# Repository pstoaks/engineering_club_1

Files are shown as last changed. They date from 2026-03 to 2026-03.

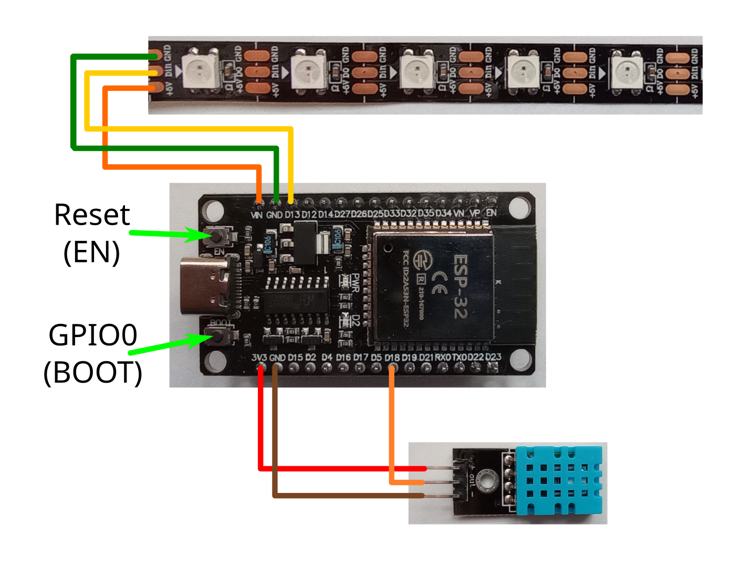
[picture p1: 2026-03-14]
docs/wiring_diagram.png

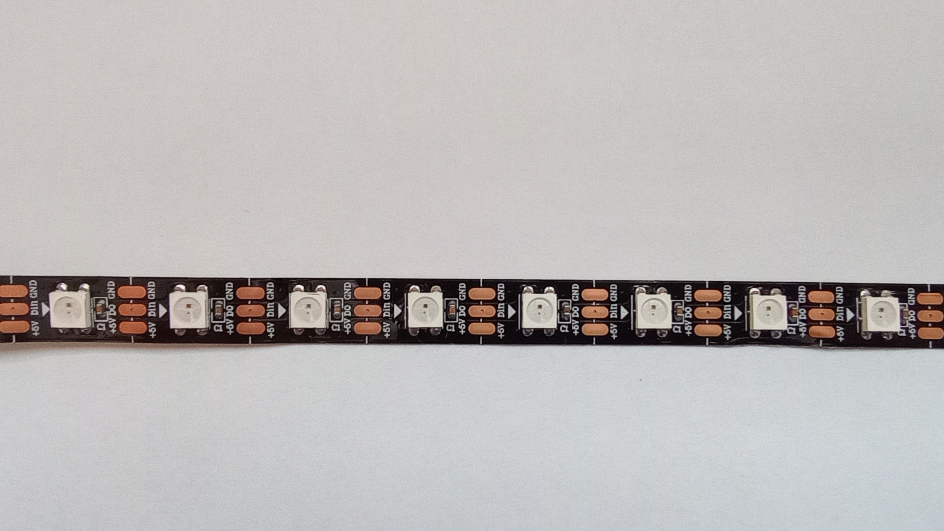
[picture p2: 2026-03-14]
docs/images/WS2812B_Light_Strip_Photo.jpg

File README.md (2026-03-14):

# Introduction to Engineering Course Plan

## 5-Week Course for Ages 12-18

### Course Overview

This course introduces students to the engineering process and disciplines (mechanical, electrical, and software) through hands-on learning. Students will build a complete IoT environmental monitor that senses temperature/humidity and displays the data using colorful LED patterns in a 3D-printed enclosure. OpenSCAD, STL and Tinkercad building blocks are provided to help with the more difficult 3D design bits.

- Week 1: Introduction to Engineering and Requirements Analysis
- Week 2: Mechanical Engineering
- Week 3: Electrical/Electronics Engineering
- Week 4: Software Development
- Week 5: Putting it all together: integration

### Learning Objectives

- Understand what engineers do in electrical, mechanical, and software disciplines
- Experience the engineering design process from requirements to final product
- Gain hands-on experience with circuits, programming, and 3D design
- Develop problem-solving and troubleshooting skills
- Make informed decisions about pursuing engineering education and careers

### Final Project

**IoT Environmental Monitor**

- ESP32 microcontroller development board
- Temperature/humidity sensor (DHT11)
- Addressable LED strip (WS2812B, 10 LEDs)
- Multiple display modes with plug-in architecture for students to design their own
- Optional web server with web application to monitor temperature and humidity and to control the mode.
- Custom, student-designed, 3D-printed enclosure
- USB power

### Purchased parts used in this course:
* ESP32 Microcontroller Development Board: https://www.amazon.com/DORHEA-Development-Bluetooth-ESP-WROOM-32-ESP32-DevKitC-32/dp/B0B18NK2MS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
* DHT11 Temperature & Humidity Sensor: https://www.amazon.com/dp/B0DTKB16MD?ref_=ppx_hzsearch_conn_dt_b_fed_asin_title_1
* WS2812B LED strip, 10 LEDs, 16.5 mm pitch.

A description of the development board being used can be found here:
https://lastminuteengineers.com/esp32-pinout-reference/

### Software Used:
  - Thonny for software development (https://thonny.org/)
  - Tinkercad for 3D modeling and design (https://www.tinkercad.com/)
  - On computers using a Microsoft Windows operating system, the CH340C driver may be required to communicate with the development board.
    - Plug the development board into the computer with a USB-C cable that supports data transfer.
    - Use Windows Device Manager to verify that a COM port has appeared, or attempt to connec to the board with Thonny.
    - If no COM port appears, or device manager states that the driver is not loaded, a driver will have to be installed.
    - The CH34XX driver can be downloaded from the manufacturer at: https://www.wch-ic.com/downloads/CH341SER_ZIP.html
    - This YouTube video describes how to install it: https://youtu.be/UUQ84VKg3oM?si=FLEs7Xpsqvz_CDct

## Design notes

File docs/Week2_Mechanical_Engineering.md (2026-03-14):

# Week 2: Mechanical Engineering - Giving It a Body: Design & Protection

## Topics

- What mechanical engineers do
- Purpose of enclosures: protection, aesthetics, usability
- Introduction to 3D design and CAD software
- Design constraints and considerations
- Iteration in design

## Activities

### Introduction (20 minutes)

Mechanical engineers should be in the class for some of this discussion. Here are some questions that we could ask of them:
- What made you select Mechanical Engineering for an education and career?
- What kind of education is require?
- Did you enjoy university? What were your favorite and least favorite parts?
- Where are you employed?
- What is your job like (a day in the life...)?
- What are your favorite and least favorite parts of the job?
- What has surprised you most about the job (vs. your expectations before your job)
- Do you have any recommendations for someone considering a job as a mechanical engineer?

What do mechanical engineers do?
- What do mechanical engineers do? Design physical systems, structures, machines
- Why does our device need an enclosure?
  - Protect electronics
  - Make it safer (cover exposed connections)
  - Look professional, cool, and/or attractive
  - Easier to use/mount
- Show examples of enclosure designs
- Discuss design constraints: must fit components, allow sensor airflow, show LEDs, access USB port, button,
  thermal considerations (such as exposing the sensor to heat dissipated by the MCU)

### Tinkercad Tutorial (20 minutes)

- Quick introduction to Tinkercad interface (browser-based, free)
- Basic operations:
  - Adding shapes
  - Moving and rotating
  - Resizing
  - Creating holes
  - Grouping
- Demonstrate measuring components and creating appropriate spaces

Demonstrate basics of building the device:
* Log in using the provided class code and your login code
* Go to the class and activity
* Duplicate the Core_Geometries design and the STL_Collection design.
* (Paul) Create a slide that identifies all of the pieces in the Core_Geometries
* Name the design
* Make a shape for the base and position it over the cylindrical cavity (hole)
    - Import your bulldog and use it to help position
    - The cavity needs to be able to completely contain the ESP32 base
* Group (Union) the cavity and the base so that the hole appears
* Make a hole solid that is the same size as the ESP32 base. Extend it, if necessary, being
  careful to ensure that the base will fit in with the USB port exposed.
* Group (Union) the base and the hole
* Flip the ESP32 base over (180) and position it in the base with the USB port
  towards the outside.
* Move the LED strip enclosure (hole) to the desired location. Should be on the left
  of the ESP32 base when looking at the USB port. Note that it must
  protrude into the cavity as we need to be able to route the wires to the ESP32.
* Flip the DHT11 base on its side. We'll need it facing out so that it can get outside air.
* Create a hole to represent the cavity that the temperature sensor needs to fit into. The cavity must
  provide room for the wires to get to the ESP32 on the USB end.
  - Ensure that you'll be able to get the module into position (manufacturability).
  - Also, think about how to protect the sensor from heat being generated by the ESP32
    module.
* Duplicate the vents (holes) as necessary and position them so that they penetrate
  the shell.
* Group to finalize the vents
* Verify that everything is the way you want it, then select the base and export it 
  as STL, ready for 3d-printing.

### Design Activity (60 minutes)

- Provide starter template file (Core_Geometries) with:
  - Basic box sized for components
  - ESP32 & DHT11 mounting solutions
  - LED strip cutout
  - Basic ventilation slots
  - Component measurements provided
- Students customize their enclosure:
  - Choose the base shape and get it into shape
  - Add ventilation holes for sensor
  - Personalize exterior (name, decorations, etc.)
  - Ensure USB port accessibility
- Save and export designs as STL files for printing

### Wrap-Up (5 minutes)

- Submit designs for review and 3D printing
- Preview: Designs will be reviewed before next week
- Mechanical engineering careers: automotive, aerospace, robotics, manufacturing, product design

## Materials Needed

- Computers with internet access (Tinkercad is web-based)
- Tinkercad accounts created (free)
- Starter template file shared with students
- Component dimension reference sheet
- Calipers or rulers for measuring components
- Example enclosures to examine
- Access to 3D printer for instructor

## Pre-Session Preparation

- Create and test starter template design
- Set up Tinkercad class/accounts
- Create slide with component descriptions
- Prepare component measurement reference sheet
- Test print starter template to verify fit
- Plan printing schedule (may need to print overnight or between sessions)
- Bring an SEL electronic device for show and tell
- Bring LED strip with WLED.
- 

## Homework/Preparation

- Optional: Learn more about 3D printing
- Study ESP32 pinout and capabilities

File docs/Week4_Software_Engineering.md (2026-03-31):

# Week 4: Software Engineering - Bringing It to Life

## Topics

- What software engineers do
- Code structure and organization
- Variables, conditionals, and functions
- Reading sensor data and controlling outputs
- Iterative development and testing
- Thonny IDE introduction

## Activities

### Introduction (10 minutes)

- What is software? Instructions that control hardware
- Overview of what the code does:
  1. Read sensor & pushbutton
  2. Process data (convert to temperature/humidity)
  3. Make decisions (if temp > X, then...)
  4. Control LEDs (colors, patterns)
  5. Repeat (super loop)
- Discuss the code structure (files and major sections).

### Guided Code Exploration (15 minutes)

- Walk through the base program section by section
- Identify key parts students will modify:
  - Calibration
  - Color mappings
  - Mode. As an extra challenge, implement a new mode!
- Demonstrate: Change one value, upload, observe result

### Hands-On Modification (30 minutes)

- Provide working base code with modification guide
- Suggested experiments (in order of complexity):
  1. Calibrate the temperature
  2. Change colors for temperatures and/or humidity
  3. Adjust temperature thresholds
  4. Fun new modes?
- Students work through modifications, testing each change
- Encourage experimentation: "What happens if...?"

### Sharing & Discussion (5 minutes)

- Quick demos of interesting modifications
- What was challenging? What was satisfying?
- Software engineering careers: app development, web development, AI/ML, embedded systems

## Materials Needed

- Assembled devices from Week 3
- Thermometer for calibration
- Base code with clear comments and modification guide
- Reference sheet with color codes (RGB values)
- Backup pre-programmed ESP32 boards

## Pre-Session Preparation

- Test base code thoroughly
- Software architecture and state machine diagrams
- Create clear modification guide with examples
- Set up code with helpful comments
- Prepare troubleshooting guide for common code errors

## Homework/Preparation

- Keep experimenting with code at home (optional)
- Think about: What would make the device more useful or cool?

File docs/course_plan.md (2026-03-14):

# Introduction to Engineering Course Plan

## 5-Week Course for Ages 12-18

### Course Overview

This course introduces students to the engineering process and disciplines (mechanical, electrical, and software) through hands-on learning. Students will build a complete IoT environmental monitor that senses temperature/humidity and displays the data using colorful LED patterns in a 3D-printed enclosure. OpenSCAD, STL and Tinkercad building blocks are provided to help with the more difficult 3D design bits.

- Week 1: Introduction to Engineering and Requirements Analysis
- Week 2: Mechanical Engineering
- Week 3: Electrical/Electronics Engineering
- Week 4: Software Development
- Week 5: Putting it all together: integration

### Learning Objectives

- Understand what engineers do in electrical, mechanical, and software disciplines
- Experience the engineering design process from requirements to final product
- Gain hands-on experience with circuits, programming, and 3D design
- Develop problem-solving and troubleshooting skills
- Make informed decisions about pursuing engineering education and careers

### Final Project

**IoT Environmental Monitor**

- ESP32 microcontroller development board
- Temperature/humidity sensor (DHT11)
- Addressable LED strip (WS2812B, 10 LEDs)
- Multiple display modes with plug-in architecture for students to design their own
- Optional web server with web application to monitor temperature and humidity and to control the mode.
- Custom, student-designed, 3D-printed enclosure
- USB power

### Purchased parts used in this course:
* ESP32 Microcontroller Development Board: https://www.amazon.com/DORHEA-Development-Bluetooth-ESP-WROOM-32-ESP32-DevKitC-32/dp/B0B18NK2MS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
* DHT11 Temperature & Humidity Sensor: https://www.amazon.com/dp/B0DTKB16MD?ref_=ppx_hzsearch_conn_dt_b_fed_asin_title_1
* WS2812B LED strip, 10 LEDs, 16.5 mm pitch.

A description of the development board being used can be found here:
https://lastminuteengineers.com/esp32-pinout-reference/

### Software Used:
  - Thonny for software development (https://thonny.org/)
  - Tinkercad for 3D modeling and design (https://www.tinkercad.com/)
  - On computers using a Microsoft Windows operating system, the CH340C driver may be required to communicate with the development board.
    - Plug the development board into the computer with a USB-C cable that supports data transfer.
    - Use Windows Device Manager to verify that a COM port has appeared, or attempt to connec to the board with Thonny.
    - If no COM port appears, or device manager states that the driver is not loaded, a driver will have to be installed.
    - The CH34XX driver can be downloaded from the manufacturer at: https://www.wch-ic.com/downloads/CH341SER_ZIP.html
    - This YouTube video describes how to install it: https://youtu.be/UUQ84VKg3oM?si=FLEs7Xpsqvz_CDct

---

## Week 1: Introduction & Requirements Analysis

### Topics

- Class overview: What are we going to be doing? (Syllabus)
- What is engineering? Problem-solving and design.
- Overview of electrical, mechanical, and software engineering disciplines
- Introduction to the engineering design process
- Requirements analysis and specification

### Activities

**Introduction (15 minutes)**

- Instructor introduction: Short (5 min) overview of education and experience.
- Class overview using the syllabus.
- Introductions around the room. What's your handle?
- What is engineering? Discussion of engineering as creative problem-solving. Requirements -> Design -> Implement -> Test.
  * Draw a diagram showing how the design progresses through the process and how the engineer incorporates science
    and technology to create the design.
  * Test what you fly, fly what you test. What do you think this means?
- Show completed IoT environmental monitor example
- Explain how all three disciplines work together to create this device

**Requirements Analysis (20 minutes)**

- Introduce the concept: "Before building anything, engineers must understand what they're building and why"
- Guided exercise: Define requirements for our device. One or more huddles to discuss these.
  - **The Need**: We need a product that is attractive and suitable for inclusion in a child's room that is capable of displaying temperature and humidity visually (at a glance) and via WiFI.
  - **Functional requirements**: What must it do?
    - Measure temperature
    - Measure humidity
    - Display data visually (with LEDs)
    - Pushbutton for user interaction (mode selection)
    - Be powered by USB
    - Update readings regularly
    - Labeling, overlay, etc.
  - **Non-functional (performance) requirements**: How well must it work?
    - Accuracy
    - Response time
    - Durability (thermal, vibration, shock, electrical immunity)
    - Size & weight constraints
    - Electromagnetic susceptibility
    - User-friendliness
    - Aesthetics
  - **Constraints**: What limits us?
    - Manufacturability
    - Regulations (safety, electromagnetic emissions, DO-178 for software, medical)
    - Budget (affects component selection, team size, manufacturing options, etc.) One-time costs vs. per-unit costs.
    - Time (5 weeks)
    - Skill level
    - Available components

**Component Exploration (20 minutes)**

- Unbox and examine components
**STATIC ELECTRICITY KILLS ELECTRONICS**
**Be Gentle, please!**
   * ESP32: The "brain" (software engineering)
   * DHT11 sensor: The "senses" (electrical engineering)
   * LED strip: The "display" (electrical engineering)
   * Enclosure: The "body" (mechanical engineering)
   * Software: Invisible stuff inside. Infinitely malleable.
   * Identify how each component addresses our requirements

**Discipline Breakdown (5 minutes)**

- Map each requirement to the engineering discipline that addresses it
- Preview what we'll learn each week (mechanical, electrical, software)

### Materials Needed

- Completed example device
- Component kits for each student (don't open yet)
- Whiteboard/screen for requirements discussion
- Any slides? Or are we better off drawing the diagrams as needed in order
  to keep it more interactive?
- Extra of everything (dev boards, dupont wires, DHT11s, etc.)

### Homework/Preparation

- Think about: What questions do you have about the project?
- Think about: What do you want your device to look like? (The shape of the base and any decoration.)
- Optional: Research what ESP32 boards are used for in real products
- Optional: Lookup Python and CircuitPython on the web
- Optional: Play with Tinkercad at home.

------

## Week 2: Mechanical Engineering - Giving It a Body: Design & Protection

### Topics

- What mechanical engineers do
- Purpose of enclosures: protection, aesthetics, usability
- Introduction to 3D design and CAD software
- Design constraints and considerations
- Iteration in design

### Activities

**Introduction (10 minutes)**

- What do mechanical engineers do? Design physical systems, structures, machines
- Why does our device need an enclosure?
  - Protect electronics
  - Make it safer (cover exposed connections)
  - Look professional, cool, and/or attractive
  - Easier to use/mount
- Show examples of enclosure designs
- Discuss design constraints: must fit components, allow sensor airflow, show LEDs, access USB port, button,
  thermal considerations (such as exposing the sensor to heat dissipated by the MCU)

**Tinkercad Tutorial (20 minutes)**

- Quick introduction to Tinkercad interface (browser-based, free)
- Basic operations:
  - Adding shapes
  - Moving and rotating
  - Resizing
  - Creating holes
  - Grouping
- Demonstrate measuring components and creating appropriate spaces

Demonstrate basics of building the device:
* Duplicate the Core_Geometries sketch
* (Paul) Create a slide that identifies all of the pieces in the Core_Geometries
* Name the design
* Make a shape for the base and position it over the cylindrical cavity (hole)
    - Import your bulldog and use it to help position
    - The cavity needs to be able to completely contain the ESP32 base
* Group (Union) the cavity and the base so that the hole appears
* Make a hole solid that is the same size as the ESP32 base. Extend it, if necessary, being
  careful to ensure that the base will fit in with the USB port exposed.
* Group (Union) the base and the hole
* Flip the ESP32 base over (180) and position it in the base with the USB port
  towards the outside.
* Move the LED strip enclosure (hole) to the desired location. Should be on the left
  of the ESP32 base when looking at the USB port. Note that it must
  protrude into the cavity as we need to be able to route the wires to the ESP32.
* Flip the DHT11 base on its side. We'll need it facing out so that it can get outside air.
* Create a hole to represent the cavity that the temperature sensor needs to fit into. The cavity must
  provide room for the wires to get to the ESP32 on the USB end.
  - Ensure that you'll be able to get the module into position (manufacturability).
  - Also, think about how to protect the sensor from heat being generated by the ESP32
    module.
* Duplicate the vents (holes) as necessary and position them so that they penetrate
  the shell.
* Group to finalize the vents
* Verify that everything is the way you want it, then select the base and export it 
  as STL, ready for 3d-printing.

**Design Activity (60 minutes)**

- Provide starter template file (Core_Geometries) with:
  - Basic box sized for components
  - ESP32 & DHT11 mounting solutions
  - LED strip cutout
  - Basic ventilation slots
  - Component measurements provided
- Students customize their enclosure:
  - Choose the base shape and get it into shape
  - Add ventilation holes for sensor
  - Personalize exterior (name, decorations, etc.)
  - Ensure USB port accessibility
- Save and export designs as STL files for printing

**Wrap-Up (5 minutes)**

- Submit designs for review and 3D printing
- Preview: Designs will be reviewed before next week
- Mechanical engineering careers: automotive, aerospace, robotics, manufacturing, product design

### Materials Needed

- Computers with internet access (Tinkercad is web-based)
- Tinkercad accounts created (free)
- Starter template file shared with students
- Component dimension reference sheet
- Calipers or rulers for measuring components
- Example enclosures to examine
- Access to 3D printer for instructor

### Pre-Session Preparation

- Create and test starter template design
- Set up Tinkercad class/accounts
- Create slide with component descriptions
- Prepare component measurement reference sheet
- Test print starter template to verify fit
- Plan printing schedule (may need to print overnight or between sessions)
- Bring an SEL electronic device for show and tell
- Bring LED strip with WLED.
- 

### Homework/Preparation

- Optional: Learn more about 3D printing
- Study ESP32 pinout and capabilities

--------

## Week 3: Electrical Engineering - Making Connections

### Topics

- Basic electrical concepts: circuits, voltage, current, signals, ohms law
- Reading wiring diagrams
- Component interfaces (I2C, digital pins)
- Troubleshooting electrical connections
- Introduction to test equipment (DVM, oscilloscope, logic analyzer, etc.)

### Activities

**Conceptual Introduction (10 minutes)**

- What do electrical engineers do?
- Basic concepts explained through analogy:
  - Voltage = pressure in a water pipe
  - Current = flow of water
  - Circuit = complete loop
  - Ohms Law
- Why proper connections matter
  - The importance of conventions (which we're not following)
- Overview of hardware architecture:
  - ESP32 dev board schematic, pinout, etc.
  - WS2812B (neopixel) schematic and description. How does it work and communicate?
  - DHT11 description. How does it work and communicate?

**Guided Wiring Activity (40 minutes)**

- Provide clear, color-coded wiring diagram
- Step-by-step connection process:
  1. Identify power rails on breadboard
  2. Connect ESP32 to breadboard
  3. Connect temperature/humidity sensor (3-4 wires)
  4. Connect LED strip (3 wires: power, ground, data)
- Checkpoints: Verify each connection before proceeding
- Load pre-written test code to ESP32
- Verify everything works (sensor reads, LEDs light up)

**Troubleshooting (5 minutes)**

- Common issues and solutions
- How to systematically check connections
- Using the serial monitor to see sensor data

**Career Discussion (5 minutes)**

- What electrical engineers do: power systems, circuit design, electronics, telecommunications
- Real-world applications

### Materials Needed

- ESP32 development boards (pre-soldered headers recommended)
- DHT11, DHT22, or DS18B20
- WS2812B LED strips (8-12 LED segments)
- Breadboards (May not be necessary depending on header availability and necessary dupont wires.)
- Jumper wires (color-coded set)
- USB cables
- Pre-written test code
- Clear wiring diagrams (printed or on screen)

### Pre-Session Preparation

- ESP32 pinout and feature slides prepared.
- Example ESP32 applications
- Hardware architecture and wiring diagram slides prepared.
- WS2812B introduction: https://www.elecfreaks.com/blog/post/get-to-know-ws2812b.html
- Test all components beforehand
- Load test code on one device to demonstrate
- Prepare backup components

### Homework/Preparation

- Keep device safe for next week
- Optional: Observe what happens when you change temperature (breathe on sensor, use ice pack)

---

## Week 4: Software Engineering - Bringing It to Life

### Topics

- What software engineers do
- Code structure and organization
- Variables, conditionals, and functions
- Reading sensor data and controlling outputs
- Iterative development and testing
- Thonny IDE introduction

### Activities

**Introduction (10 minutes)**

- What is software? Instructions that control hardware
- Overview of what the code does:
  1. Read sensor & pushbutton
  2. Process data (convert to temperature/humidity)
  3. Make decisions (if temp > X, then...)
  4. Control LEDs (colors, patterns)
  5. Repeat (super loop)
- Discuss the code structure (files and major sections).

**Guided Code Exploration (15 minutes)**

- Walk through the base program section by section
- Identify key parts students will modify:
  - Temperature thresholds
  - Color mappings
  - LED patterns
  - Update frequency
  - Mode
- Demonstrate: Change one value, upload, observe result

**Hands-On Modification (30 minutes)**

- Provide working base code with modification guide
- Suggested experiments (in order of complexity):
  1. Calibrate the temperature
  2. Change color for "cold" temperature range
  3. Adjust temperature thresholds
  4. Change LED animation speed
  5. Modify humidity color mapping
  6. Create custom color pattern
  7. Add new temperature range/color
  8. Fun new modes?
- Students work through modifications, testing each change
- Encourage experimentation: "What happens if...?"

**Sharing & Discussion (5 minutes)**

- Quick demos of interesting modifications
- What was challenging? What was satisfying?
- Software engineering careers: app development, web development, AI/ML, embedded systems

### Materials Needed

- Assembled devices from Week 3
- Thermometer for calibration
- Base code with clear comments and modification guide
- Reference sheet with color codes (RGB values)
- Backup pre-programmed ESP32 boards

### Pre-Session Preparation

- Test base code thoroughly
- Software architecture and state machine diagrams
- Create clear modification guide with examples
- Set up code with helpful comments
- Prepare troubleshooting guide for common code errors

### Homework/Preparation

- Keep experimenting with code at home (optional)
- Think about: What would make the device more useful or cool?

---

## Week 5: Integration, Testing & Future Pathways

### Topics

- System integration
- Testing and troubleshooting
- Engineering careers and education pathways
- Reflection on the engineering design process

### Activities

**Assembly (15 minutes)**

- Distribute printed enclosures
- Install devices in enclosures
- Cable management
- Final assembly checks

**Testing & Troubleshooting (15 minutes)**

- Does everything still work?
- Systematic testing approach:
  - Power on
  - Check sensor readings
  - Verify LED display
  - Test pushbutton and modes
  - Test in different conditions
- Problem-solving session for any issues
- Make final code adjustments if desired

**Demonstrations (15 minutes)**

- Each student briefly shows their device (1-2 minutes each)
- What customizations did you make?
- What are you most proud of?
- What would you improve?

**Reflection & Future Pathways (15 minutes)**

- Discussion questions:
  - Which discipline interested you most? Why?
  - What was the most challenging part?
  - What did you learn about how engineers work together?
  - How does this project compare to what you thought engineering was?
- Education pathways:
  - High school: Math, physics, computer science classes
  - College: Engineering programs, what to expect
  - Alternatives: Bootcamps, trade schools, self-learning
  - Industry certifications
- Resources for continued learning
- Optional: Q&A with guest engineers (if available)

### Materials Needed

- 3D printed enclosures
- Completed devices from previous weeks
- Any final assembly tools needed
- Backup components for troubleshooting
- Career/education resource handouts
- Certificates of completion (optional)

### Pre-Session Preparation

- Complete all 3D prints
- Test fit one complete assembly
- Prepare education/career resources
- Arrange guest speakers if possible
- Create any certificates or completion documentation

### Follow-Up

- Provide resource list for continued learning
- Encourage students to provide feedback
- Keep in touch with interested students about future opportunities

---

## Materials & Budget Summary

### Per Student Kit

- ESP32 development board: $8-12
- DHT22 or BME280 sensor: $5-10
- WS2812B LED strip (8-12 LEDs): $3-5
- Breadboard: $3-5
- Jumper wires set: $3-5
- USB cable: $3-5
- 3D printed enclosure: $2-5 (filament cost)
- **Total per student: ~$27-47**

### Shared Resources

- Computers with Arduino IDE
- 3D printer access
- Backup components
- Tools (wire strippers, calipers, etc.)

### Software (All Free)

- Arduino IDE
- Tinkercad
- Required Arduino libraries (FastLED, DHT or Adafruit BME280)

---

## Instructor Preparation Checklist

### Before Week 1

- [ ] Order all components with extras for backup
- [ ] Build and test one complete example device
- [ ] Prepare requirements analysis discussion materials

### Before Week 2

- [ ] Test all components
- [ ] Pre-solder headers to ESP32 boards (if needed)
- [ ] Install Arduino IDE on all computers
- [ ] Install ESP32 board support and libraries
- [ ] Create and test wiring diagrams
- [ ] Write and test verification code
- [ ] Prepare troubleshooting guide

### Before Week 3

- [ ] Write base code with clear modification points
- [ ] Test all modification examples
- [ ] Create modification guide document
- [ ] Prepare RGB color reference sheet
- [ ] Load base code on backup ESP32 boards

### Before Week 4

- [ ] Create and test Tinkercad starter template
- [ ] Set up Tinkercad class accounts
- [ ] Prepare component measurement reference
- [ ] Test print starter design
- [ ] Plan printing schedule
- [ ] Ensure 3D printer is calibrated and ready

### Before Week 5

- [ ] Complete all 3D prints
- [ ] Test fit assembly
- [ ] Prepare career/education resources
- [ ] Arrange guest speakers (if applicable)
- [ ] Create certificates or completion documentation

---

## Tips for Success

### Time Management

- Build in buffer time for troubleshooting
- Have backup activities if students finish early
- Be prepared to adjust pacing based on class progress

### Differentiation

- Advanced students: Suggest additional features or customizations
- Struggling students: Provide extra support, use buddy system
- Have extension activities ready

### Safety

- Emphasize proper handling of electronics
- USB power only (safe low voltage)
- Supervise 3D printer operation
- Hot glue gun safety if used for final assembly

### Engagement

- Encourage questions and experimentation
- Celebrate failures as learning opportunities
- Make connections to real-world applications
- Share stories of engineering careers and innovations

### Documentation

- Take photos of student work for portfolios
- Document issues and solutions for future iterations
- Collect student feedback for course improvement

---

## Possible Extensions

If students are interested in continuing beyond the 5 weeks:

- Add a display screen (OLED) to show numerical readings
- Implement WiFi connectivity to log data online
- Add more sensors (light, air quality, etc.)
- Create a mobile app to monitor the device
- Design a more complex multi-part enclosure
- Implement battery power for portability
- Add user controls (buttons to change modes)

---

## Assessment Ideas (Optional)

- Participation and engagement
- Successful completion of weekly activities
- Creativity in customizations
- Ability to troubleshoot and problem-solve
- Quality of final presentation
- Reflection on learning and interests

---

## Resources for Students

### Online Learning

- Arduino Project Hub: https://create.arduino.cc/projecthub
- Tinkercad Tutorials: https://www.tinkercad.com/learn
- Khan Academy: Computer Programming and Physics

### Communities

- Local maker spaces
- Robotics clubs
- Online forums (Arduino, maker communities)

### Books

- "Make: Electronics" by Charles Platt
- "Python Crash Course" by Eric Matthes
- "The Way Things Work Now" by David Macaulay

---

## Notes for Future Iterations

_Use this section to document what worked well, what needs improvement, and ideas for future versions of the course._

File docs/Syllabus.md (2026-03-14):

# Future Builders: Introduction to Engineering

**Ages:** 12-18 **Duration:** 5 weeks **Format:** Hands-on project-based learning

## Course Description
This hands-on course introduces students to electrical, mechanical, and software engineering through building a complete IoT environmental monitor. Students will create a device that senses temperature and humidity, displays data using colorful LED patterns, and lives in a custom 3D-printed enclosure.

## Learning Objectives
- Experience the complete engineering design process from requirements to final product
- Understand what engineers do in electrical, mechanical, and software disciplines
- Gain practical skills in circuits, programming, and 3D design
- Develop problem-solving and troubleshooting abilities
- Make informed decisions about pursuing engineering education and careers

## Weekly Schedule
### Week 1: Introduction & Requirements Analysis
Introduction to engineering disciplines • Engineering design process • Project requirements analysis • Component exploration

### Week 2: Mechanical Engineering - Giving It a Skeleton and Skin
Purpose and design of enclosures • Introduction to 3D CAD (Tinkercad) • Custom enclosure design • Preparing designs for 3D printing

### Week 3: Electrical Engineering - Making Connections
Basic circuits and electrical concepts • Reading wiring diagrams • Hands-on circuit wiring • Component integration • Troubleshooting connections

### Week 4: Software Engineering - Bringing It to Life
Introduction to programming concepts • Code structure and organization • Reading sensors and controlling LEDs • Hands-on code modification and experimentation

### Week 5: Putting It All Together
Final assembly • System testing and troubleshooting • Project demonstrations • Career and education pathways • Reflection and next steps

## Materials Provided
Each student receives a complete kit including ESP32 microcontroller, temperature and humidity sensor, addressable LED strip, wiring, and custom 3D-printed enclosure. All software is free and open-source.

## What to Bring
- Curiosity and willingness to experiment
- Notebook for ideas and observations

## Resources
All course materials, code templates, and design files will be provided. Students will leave with a complete working device and knowledge to continue learning independently.

----------------------------------------------------------------------

**Questions?** Contact the library before the first session. We look forward to engineering with you!

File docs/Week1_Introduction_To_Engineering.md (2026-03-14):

# Week 1: Introduction & Requirements Analysis

## Topics

- Class overview: What are we going to be doing? (Syllabus)
- What is engineering? Problem-solving and design.
- Overview of electrical, mechanical, and software engineering disciplines
- Introduction to the engineering design process
- Requirements analysis and specification

## Activities

### Introduction (15 minutes)

- Instructor introduction: Short (5 min) overview of education and experience.
- Class overview using the syllabus.
- Introductions around the room. What's your handle?

### What is Engineering? (20 minutes)
- What is engineering? 
  * Discussion of engineering as disciplined creative problem-solving. What makes it different from "hacking"?
  * Requirements -> Design -> Implement -> Test.
  * Draw a diagram showing how the design progresses through the process and how the engineer incorporates science
    and technology to create the design.
  * Discuss the engineering disciplines and how they fit in. Each discipline has its own processes for Design->Implement->Test.
  * Test what you fly, fly what you test. What do you think this means?
- Show completed IoT environmental monitor example
- Explain how all three disciplines work together to create this device

### Requirements Analysis (40 minutes)

- Introduce the concept: "Before building anything, engineers must understand what they're building and why"
- Guided exercise: Define requirements for our device. One or more huddles to discuss these.
  - **The Need**: 
    - We need a product that is attractive and suitable for inclusion in a child's room that is capable of displaying temperature and humidity visually (at a glance) and via WiFI. The incorporation of a game would be "cool".
    - Instructor poses as "Product Engineer" who can describe the desired product, but not detailed engineering requirements. 
    - Throughout the exercise, the students should ask the Product Engineer questions to verify their understanding of the requirements. 
  - **Functional requirements**: What must it do?
    - Measure temperature
    - Measure humidity
    - Display data visually (with LEDs)
    - Pushbutton for user interaction (mode selection)
    - Be powered by USB
    - Update readings regularly
    - Labeling, overlay, etc.
  - **Non-functional (performance) requirements**: How well must it work?
    - Accuracy
    - Response time
    - Durability (thermal, vibration, shock, electrical immunity)
    - Size & weight constraints
    - Electromagnetic susceptibility
    - User-friendliness
    - Aesthetics
  - **Constraints**: What limits us?
    - Manufacturability
    - Regulations (safety, electromagnetic emissions, DO-178 for software, medical)
    - Budget (affects component selection, team size, manufacturing options, etc.) One-time costs vs. per-unit costs.
    - Time (5 weeks)
    - Skill level
    - Available components

### Specification and Preliminary Design (20 minutes)
  - Summarize the requirements in each area
  - How are we going to meet each requirement?
  - What components will we need?
  - What will need to do (tasks) to implement, test, and manufacture our design?

### Component Exploration (10 minutes)
- Unbox and examine components
**STATIC ELECTRICITY KILLS ELECTRONICS**
**Be Gentle, please!**
   * ESP32: The "brain" (electrical engineering, software engineering)
   * DHT11 sensor: The "senses" (electrical engineering)
   * LED strip: The "display" (electrical engineering)
   * Enclosure: The "body" (mechanical engineering)
   * Software: Invisible stuff inside. Infinitely malleable.
   * Identify how each component addresses our requirements

### Discipline Breakdown (10 minutes)
- Map each identified task to the engineering discipline(s) that execute it
- Preview what we'll learn each week (mechanical, electrical, software)

### Time Filler (if needed)
- Introduce and demonstrate Tinkercad.

## Materials Needed

- Completed example device
- Component kits for each student
- Whiteboard/screen for requirements discussion
- Any slides? Or are we better off drawing the diagrams as needed in order
  to keep it more interactive?
- Extra of everything (dev boards, dupont wires, DHT11s, etc.)

## Homework/Preparation

- Think about: What questions do you have about the project?
- Think about: What do you want your device to look like? (The shape of the base and any decoration.)
- Optional: Research what ESP32 boards are used for in real products
- Optional: Lookup Python and CircuitPython on the web
- Optional: Play with Tinkercad at home.

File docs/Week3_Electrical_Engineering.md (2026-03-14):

# Week 3: Electrical Engineering - Making Connections

## Topics

- What do electrical engineers do?
- Basic electrical concepts: circuits, voltage, current, signals, ohms law
- Logic concepts (boolean/binary, AND, OR, NOT)
- Reading wiring diagrams
- Component interfaces (I2C, digital pins)
- Troubleshooting electrical connections
- Introduction to test equipment (DVM, oscilloscope, logic analyzer, etc.)

## Activities

*There are only six wires to be connected for this design. As a result, the hands-on time requirements are minimal. This can be advantageous if the students need more time with Tinkercad to finish their enclosure designs from Week 2. The instructor can adjust the activities this week to provide time for completing the mechanical design.*

### Conceptual Introduction (20 minutes)

- Basic concepts explained through analogy:
  - Voltage = pressure in a water pipe
  - Current = flow of water
  - Circuit = complete loop
  - Ohms Law
- Digital Logic
  - Microcontrollers: Introduction to the ESP32
  - Boolean/binary values, AND, OR, NOT
  - GPIO usage
  - Serial buses (I2C, SPI, WS2812B, and One-Wire)
- Sensing and Controlling
  - Sensors (voltage, current, temperature, pressure, humidity, position, strain, distance, etc.)
  - Controlling (motors, resistive loads, optocouplers, voltage translators, etc.)
- Overview of hardware architecture:
  - ESP32 dev board schematic, pinout, etc.
  - WS2812B (neopixel) schematic and description. How does it work and communicate?
  - DHT11 description. How does it work and communicate?

### Guided Wiring Activity (40 minutes)

- Provide clear, color-coded wiring diagram
- Step-by-step connection process:
  1. Connect temperature/humidity sensor (3 wires)
  2. Connect LED strip (3 wires: power, ground, data)
- Checkpoints: Verify each connection before proceeding
- Plug in USB cable **Gently!**
- Verify test results by executing test procedure

**Connections Table**

| ESP32 Board Pin | Device Pin  | Wire Color  | Purpose |
|---:|:---|:---|:---|
| **LED Strip** | | | |
| VIN | LED +5V | Orange | +5V to LED Strip  |
| GND | LED GND | Green | LED Strip Ground  |
| D13 | LED Din | Yellow | LED Strip Data |
| **DHT11 Sensor**  | | | |
| 3V3 | + | Red | DHT11 3.3V Supply |
| GND | - | Brown | DHT11 Ground |
| D18 | out | Orange | DHT11 Data |

### Troubleshooting (5 minutes)

- Common issues and solutions
- How to systematically check connections
- Using the serial monitor to see sensor data

### Career Discussion (20 minutes)

- What electrical engineers do: design and test power systems, circuit design, electronics, telecommunications

Electrical or computer engineers should be in the class for some of this discussion. Choose folks who have experience designing and testing mirocontroller based electronic devices. Here are some questions that we could ask of them:
- What made you select Electrical/Computer Engineering for an education and career?
- What kind of education is require?
- Did you enjoy university? What were your favorite and least favorite parts?
- Where are you employed?
- What is your job like (day in the life...)?
- What are your favorite and least favorite parts of the job?
- What has surprised you most about the job (vs. your expectations before your job)
- Do you have any recommendations for someone considering a job as an engineer?

## Materials Needed

- ESP32 development boards with pre-soldered headers
- DHT11 breakout board
- WS2812B LED strips (10 LED segments)
- USB cables
- Pre-written test code
- Clear wiring diagrams (printed or on screen)
- Materials for general electrical circuit discussion
- Materials for microcontroller interfacing discussion
  - GPIO to drive LEDs, relays, etc.
  - Binary
  - Serial bus operation (oscilloscope and/or logic analyzer to show communication protocol)
- Materials for ESP32 discussion
- Test Plan/Procedure!

## Pre-Session Preparation

- ESP32 pinout and feature slides prepared.
- Example ESP32 applications
- Hardware architecture and wiring diagram slides prepared.
- WS2812B introduction: https://www.elecfreaks.com/blog/post/get-to-know-ws2812b.html
- Test all components beforehand
- Create test plan
- Prepare backup components

## Homework/Preparation

- Keep device safe for next week
- Optional: Observe what happens when you change temperature (breathe on sensor, use ice pack)

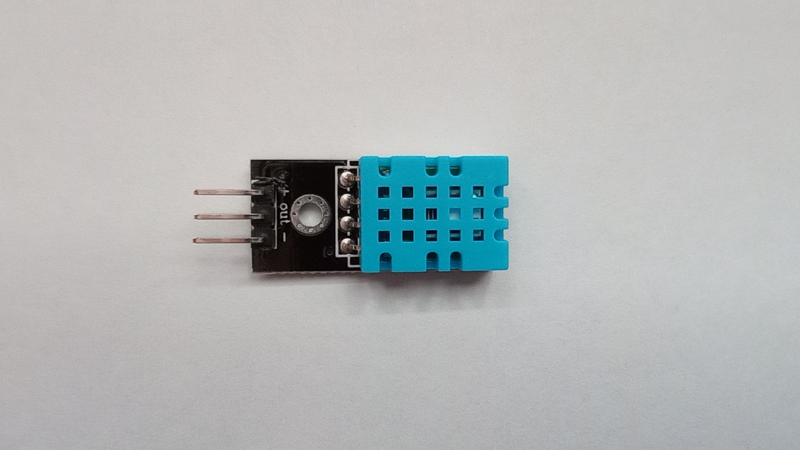
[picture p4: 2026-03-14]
docs/images/DHT11_Breakout_Photo.jpg

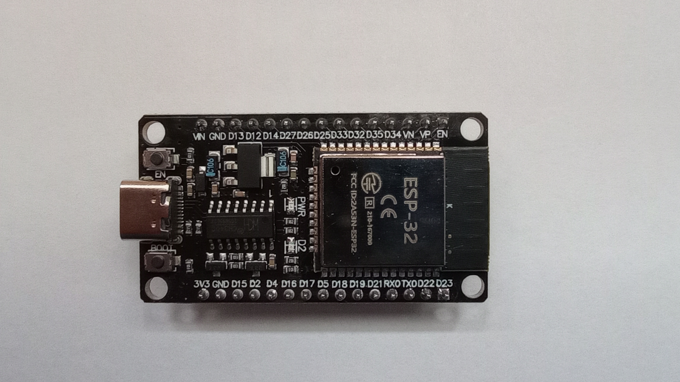
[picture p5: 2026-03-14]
docs/images/ESP32_Dev-Board_Photo.jpg

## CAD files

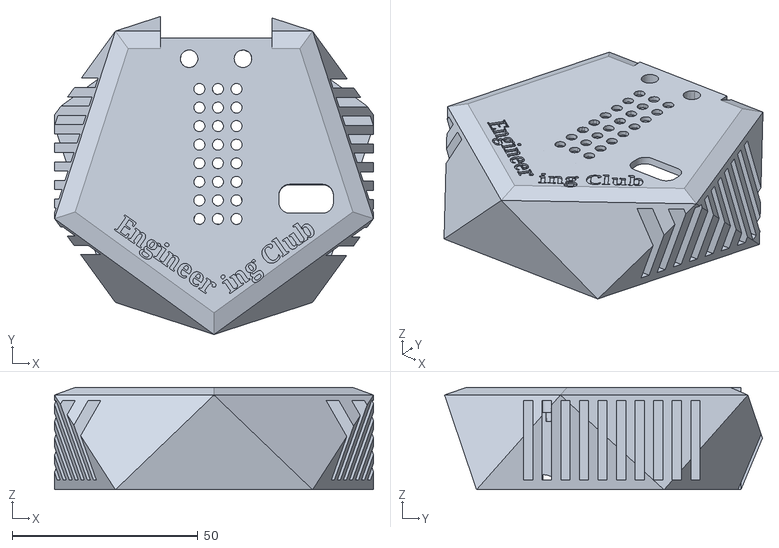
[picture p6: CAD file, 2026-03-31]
enclosure/Engineering_Club_Base.stl
85.9 x 85.6 x 27.5

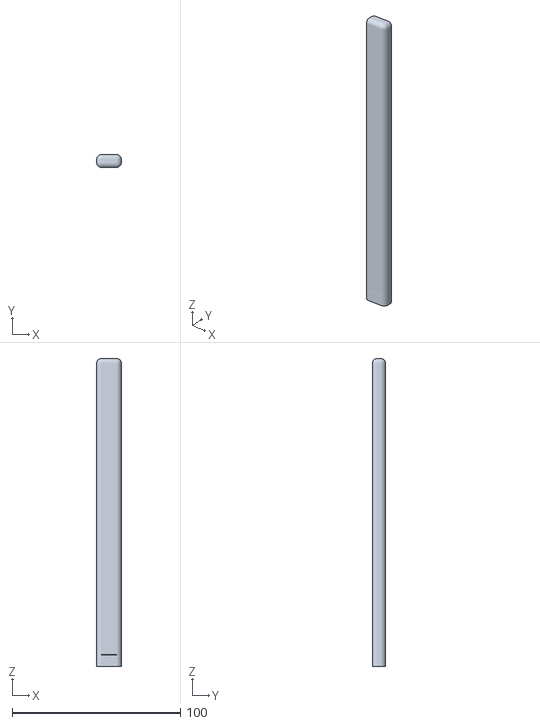
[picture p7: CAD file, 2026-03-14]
enclosure/LED_Encl_Cutout.stl
14.7 x 7.77 x 183.2

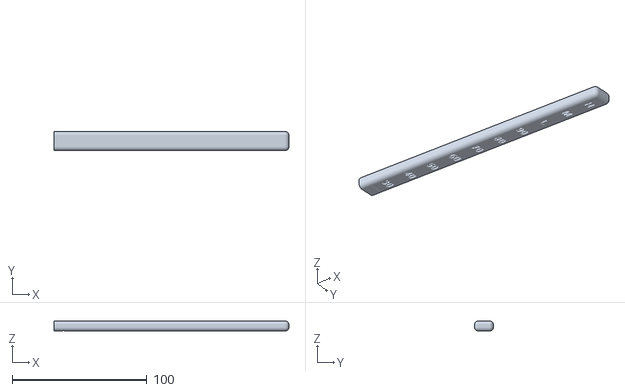
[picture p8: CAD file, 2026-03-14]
enclosure/LED_Enclosure.stl
174.4 x 14.0 x 7.40

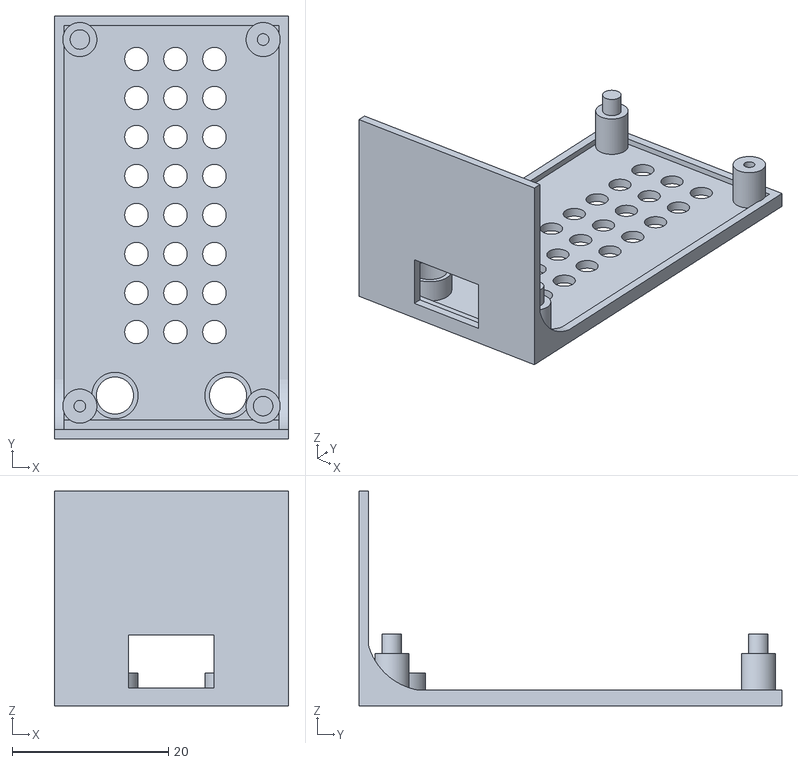
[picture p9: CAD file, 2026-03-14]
enclosure/esp32_base.stl
30.0 x 54.2 x 27.5

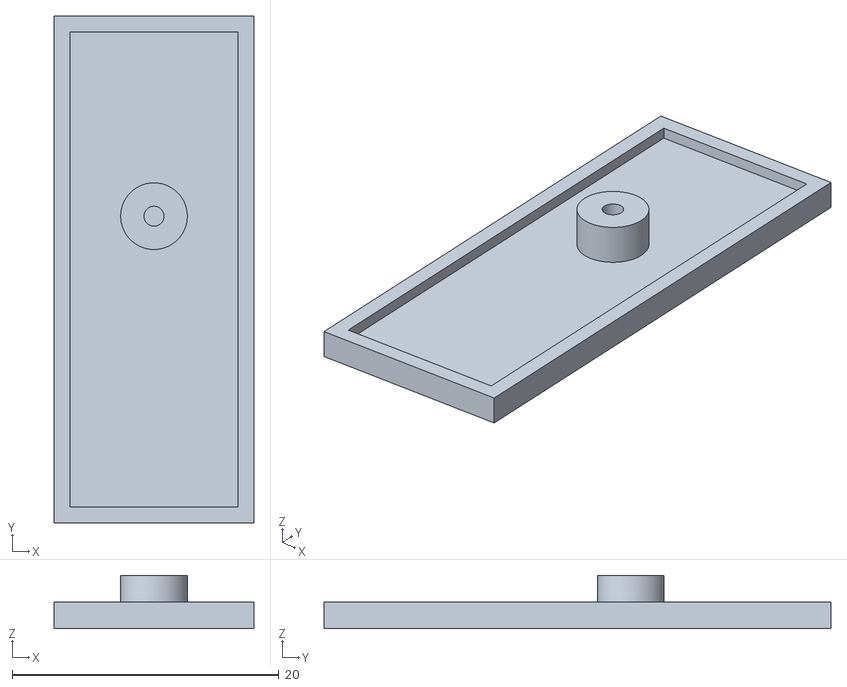
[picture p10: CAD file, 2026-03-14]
enclosure/dht11_base.stl
15.0 x 38.0 x 4.00

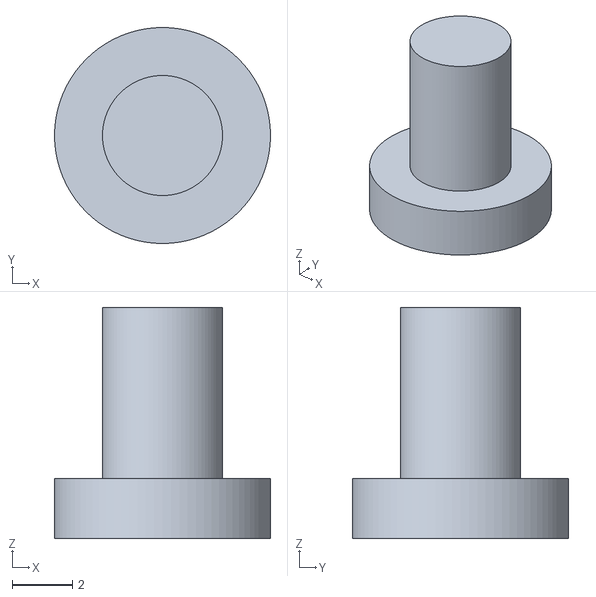
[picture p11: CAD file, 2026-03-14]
enclosure/button.stl
7.20 x 7.20 x 7.70

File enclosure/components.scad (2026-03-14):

use <rounded_cube.scad>
include <esp32_mounts.scad>

$fn = 80;
in = 25.4;
mm = 1.0;

// General 3D printing parameters
LAYER_THICKNESS = 0.28 * mm;
NOZZLE_DIA = 0.6 * mm;
WALL_THICKNESS = 2.0 * NOZZLE_DIA;     // 2 * nozzle width or roughly 4 * layer depth

BOX_WIDTH = 30 * mm;
BOX_LEN   = 53 * mm;
BOX_DEPTH = 27.5 * mm;                 // Deep enough to accommodate bend radius of dupont wires.
TARGET_BOX = [BOX_WIDTH, BOX_LEN, BOX_DEPTH];

DEV_BOARD_TYPE_IDX = ESP32_TYPEC_IDX;  // The ESP32 dev board type we're generating for. See esp32_mounts.scad library.
// I have set this to the distance from the front edge of the PCB to the center of the
// screw hole.
BOARD_OFFSET_FROM_FRONT = 3.0;         // The offset of the board edge along the Y-axis. Set to 0 to center board.
BUTTON_SHAFT_DIA = 4.0 * mm;           // The diameter of the button actuator shaft.

// DHT11 Breakout Board Dimensions
DHT11_LEN = 38.0 * mm;                 // Length of the board with dupont connectors attached (bent up)
DHT11_WIDTH = 15.0 * mm;               // Width of the board with small keepout
DHT11_DEPTH = 18.0 * mm;               // Depth with connectors attached (bent up to shorten).
DHT11_PCB_THICK = 1.5 * mm;            // The thickness of the PCB
DHT11_STANDOFF_LENGTH = 4.0 * mm;      // The length of the standoff (support height)
MOUNT_HOLE_X = DHT11_WIDTH/2.0;        // Offset of mounting hole from long edge
MOUNT_HOLE_Y = 23.0 * mm;              // Offset of mounting hole from sensor end

// LED Strip dimensions and dimensions for enclosure
NUM_LEDS = 10;                         // The number of LEDs in the strip
LED_PITCH = 16.5 * mm;                 // Pitch between LEDs
LED_STRIP_LENGTH = (NUM_LEDS) * LED_PITCH;         // Length of the LED strip
LED_STRIP_WIDTH = 10.0 * mm;           // Actually 9.5, but cavity should be this width.
LED_STRIP_DEPTH = 2.2 * mm;             // The maximum depth of the LED strip
FIRST_LED_OFFSET = 8.6 * mm;           // Distance to first LED from base of the strip
LED_ENCL_EXTENSION = 7.0 * mm;   // Enclosure extension down
LED_ENCL_LENGTH = LED_STRIP_LENGTH + LED_ENCL_EXTENSION;
LED_ENCL_FIRST_LED_OFFSET = LED_ENCL_EXTENSION + FIRST_LED_OFFSET;
NUMBER_FONT = "Arial:style=Bold";      // Check Help -> Font List for more
TEXT_DEPTH = 4*LAYER_THICKNESS;        // The text depth (engraved)

// Some useful functions
function dht11_envelope() = [DHT11_WIDTH, DHT11_LEN, DHT11_DEPTH+DHT11_STANDOFF_LENGTH];

if (0) // Render all of the objects defined here
{
   dht11_base();
   translate([dht11_envelope()[0]+10, 0, 0])
   {
      esp32_pcb_mount(dev_board_type=ESP32_BOARDS[DEV_BOARD_TYPE_IDX], 
         target_box=TARGET_BOX, 
         front_offset=BOARD_OFFSET_FROM_FRONT, 
         usb_cable_aperture=[11.0*mm, 6.8 * mm], 
         BUTTON_SHAFT_DIA, 
         WALL_THICKNESS);
      translate([TARGET_BOX[0]+10, 0, 0])
      {
         LED_Strip_Encl(false);
         translate([25, 0, 0])
            button(ESP32_BOARDS[DEV_BOARD_TYPE_IDX], BUTTON_SHAFT_DIA);
      }
   }
}

if (0)
{
   esp32_pcb_mount(dev_board_type=ESP32_BOARDS[DEV_BOARD_TYPE_IDX], 
      target_box=TARGET_BOX, 
      front_offset=BOARD_OFFSET_FROM_FRONT, 
      usb_cable_aperture=[11.0*mm, 6.8 * mm], 
      BUTTON_SHAFT_DIA, 
      WALL_THICKNESS);
}

if (1) // This is the LED strip enclosure itself, with lettering.
   rotate([90, 0, 90])
   {
      LED_Strip_Encl(false);
   }
   

if (0) // This creates a shape that is useful for creating a cutout that the LED strip enclosure fits into.
   scale([1.05, 1.05, 1.0])
      LED_Strip_Encl(true);

if (0)
   button(ESP32_BOARDS[DEV_BOARD_TYPE_IDX], BUTTON_SHAFT_DIA);

module button(dev_board_type, button_shaft_dia)
{
   BUTTON_HEAD_DIA = button_shaft_dia * 1.8;
   BUTTON_HEAD_HEIGHT = 2.0 * mm;
   BUTTON_EXTENSION = 1.5 * mm;

   union()
   {
      // Head, on the bottom
      cylinder(h=BUTTON_HEAD_HEIGHT, d=BUTTON_HEAD_DIA);
      // shaft, above
      translate([0, 0, BUTTON_HEAD_HEIGHT])
         cylinder(h=button_shaft_length(dev_board_type, WALL_THICKNESS)+BUTTON_EXTENSION, d=button_shaft_dia);
   }

} // button()

module LED_Strip_Encl(cutout = false)
{
   // Consider thicker, with offset to allow for inset lettering on the front.
   INTERNAL_MARGIN = 0.8 * mm; // Internal margin to ensure that strip will slip in.
   external_width = LED_STRIP_WIDTH + 2*WALL_THICKNESS + 2*INTERNAL_MARGIN;
   external_depth = LED_STRIP_DEPTH + 3*WALL_THICKNESS + 2*INTERNAL_MARGIN;
   edge_radius = external_width * 0.2;
   internal_width = LED_STRIP_WIDTH + 2*INTERNAL_MARGIN;
   internal_depth = LED_STRIP_DEPTH + 2*INTERNAL_MARGIN;

   difference()
   {
      roundedcube([external_width, external_depth, LED_ENCL_LENGTH+WALL_THICKNESS*2.0], false, edge_radius, "zmax");
      // Insertion depth marker
      translate([external_width/2.0, -0.1, LED_ENCL_EXTENSION])
      {
         cube([internal_width, 0.6, 0.5], true);
      } 

      if (!cutout)
      {
         // cavity
         translate([WALL_THICKNESS, 2*WALL_THICKNESS, -0.1])
         {
            cube([internal_width, internal_depth, LED_ENCL_LENGTH]);
         }

         // Lettering
         translate([external_width/2.0, TEXT_DEPTH-0.1, LED_ENCL_FIRST_LED_OFFSET])
         {
            TEMP_TEXT_SIZE = 5;

            // Temperature numbers
            for (temp = [30:10:90]) // Generate temperature numbers from 30 deg to 90 deg in steps of 10
            {
               z = (floor((temp-30)/10))*LED_PITCH;
               // echo("Temp: ", temp, " Z: ", z);
               translate([0, 0, z]) rotate([90, 0, 0])
               {
                  centered_string(str(temp), NUMBER_FONT, TEMP_TEXT_SIZE, TEXT_DEPTH);
               }
            }

            // Humidity Text
            HUMID_TEXT = ["L", "M", "H"];
            HUMID_TEXT_SIZE = 5;
            for (humid = [0:2]) // Generate humidity indices
            {
               zh = (humid+7)*LED_PITCH;
               translate([0, 0, zh]) rotate([90, 0, 0])
               {
                  centered_string(HUMID_TEXT[humid], NUMBER_FONT, HUMID_TEXT_SIZE, TEXT_DEPTH);
               }
            }
         }
      }
   }

} // LED_Strip_Encl()

module centered_string(text, font, size, height)
{
   // The text will be centered horizontally and vertically
   // text: The text to create
   // font: The font specification
   // size: The size of the text (XY-plane)
   // height: The 3D height of hte text (z-axis)
   linear_extrude(height)
   {
      text(text, size = size, font = font, halign = "center", valign = "center", $fn = 64);
   }

}  // centered_string()

module dht11_base()
{
   SCREW_HOLE_DIA = 1.5 * mm;
   STANDOFF_DIA = 5.0 * mm;
   STANDOFF_HOLE_DIA = 1.5 * mm;

   // Using "cover" module to ensure correct fit with the cover, if used.
   // width, length, and depth are outer dimensions
   cover([DHT11_WIDTH, DHT11_LEN, 2.0], WALL_THICKNESS, false);

   // Standoff
   translate([MOUNT_HOLE_X, MOUNT_HOLE_Y, 0])
   {
      standoff_with_hole(STANDOFF_HOLE_DIA, STANDOFF_DIA, DHT11_STANDOFF_LENGTH, DHT11_STANDOFF_LENGTH);
   }
   
} // dht11_base()

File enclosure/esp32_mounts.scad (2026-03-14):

// Defines parameters of different ESP32 development boards
// and modules to generate mounting for them.

$fn = 80;
in = 25.4;
mm = 1.0;

// PCB "struct" constructor
function esp32_dev_board(
    pcb_thick,                         // PCB thickness
    standoff_pin_dia,                  // Locating pin dia (just a little smaller than the mounting hole dia)
    standoff_hole_dia,                 // Screw pilot hole dia
    standoff_support_height,           // The distance the board should be supported off the base (consider screw length)
    standoff_rect,                     // Array. X and Y distances beteween standoffs
    usb_port_width,                    // The width of the USB port on the PCB (not the opening width)
    usb_x_offset,                      // Offset to the center of the USB port from the center of the mounting hole
    usb_z_offset,                      // Height of connector above the top of the board.
    button_width,                      // Width (X-dimension) of the buttons on the board
    button_offset_x,                   // Center of button from center of standoff (X-dimension). Buttons are assumed to be symmetrical around center.
    button_offset_y,                   // Center of button from center of standoff (Y)
    button_height                     // Allow this for the height of the un-pressed button
) = [
      pcb_thick,
      standoff_pin_dia,
      standoff_hole_dia,
      standoff_support_height,
      standoff_rect,
      usb_port_width,
      usb_x_offset,
      usb_z_offset,
      button_width,
      button_offset_x,
      button_offset_y,
      button_height
];

// Accessors
function pcb_thick(p)                  = p[0];
function pcb_standoff_pin_dia(p)       = p[1];
function pcb_standoff_hole_dia(p)      = p[2];
function pcb_standoff_support_height(p)= p[3];
function pcb_standoff_rect(p)          = p[4];
function pcb_usb_port_width(p)         = p[5];
function pcb_usb_x_offset(p)           = p[6];
function pcb_usb_z_offset(p)           = p[7];
function pcb_button_width(p)           = p[8];
function pcb_button_offset_x(p)        = p[9];
function pcb_button_offset_y(p)        = p[10];
function pcb_button_height(p)          = p[11];
function button_shaft_length(p, wall_thickness) = pcb_standoff_support_height(p) + wall_thickness - pcb_button_height(p);
function pin_x_offset(p, target_box) = (target_box[0]-pcb_standoff_rect(p)[0])/2.0;
function pin_y_offset(p, front_offset, target_box) = (front_offset > 0.0) ? front_offset : (target_box[1]-pcb_standoff_rect(p)[1])/2.0;


// These index constants are indexes into the ESP32_BOARDS
// array, so they must be kept in the same order as the entries there.
ESP32_DEVKITV1_IDX = 0;                 // https://www.amazon.com/dp/B08D5ZD528?ref_=ppx_hzsearch_conn_dt_b_fed_asin_title_13&th=1
ESP32_TYPEC_IDX = 1;                    // https://www.amazon.com/dp/B0B18NK2MS?ref_=ppx_hzsearch_conn_dt_b_fed_asin_title_1&th=1
ESP32S3_USB_IDX = 2;                    // https://www.amazon.com/dp/B0DG8L7MQ9?ref_=ppx_hzsearch_conn_dt_b_fed_asin_title_3&th=1

ESP32_BOARDS= [
   esp32_dev_board( // ESP32_DEVKITV1_IDX
      pcb_thick              = 1.5 * mm,
      standoff_pin_dia       = 2.3 * mm,
      standoff_hole_dia      = 1.5 * mm,
      standoff_support_height= 5.5 * mm,
      standoff_rect          = [23.7 * mm, 46.7 * mm],
      usb_port_width         = 7.45 * mm,
      usb_x_offset           = 23.7 * mm / 2.0,
      usb_z_offset           = 2.32 * mm,
      button_width           = 3.0 * mm,
      button_offset_x        = 4.0 * mm,
      button_offset_y        = 1.36 * mm,
      button_height          = 2.50 * mm
   ),
   esp32_dev_board( // ESP32_TYPEC_IDX
      pcb_thick              = 1.5 * mm,
      standoff_pin_dia       = 2.5 * mm,
      standoff_hole_dia      = 1.5 * mm,
      standoff_support_height= 5.5 * mm,
      standoff_rect          = [23.5 * mm, 47.0 * mm],
      usb_port_width         = 8.9 * mm,
      usb_x_offset           = 11.725 * mm,
      usb_z_offset           = 3.24 * mm,
      button_width           = 3.0 * mm,
      button_offset_x        = 4.5 * mm,
      button_offset_y        = 1.36 * mm,
      button_height          = 2.50 * mm
   )
]; 

module esp32_pcb_mount(dev_board_type, target_box, front_offset, usb_cable_aperture, button_shaft_dia, wall_thickness)
{
   // Creates an enclosure that has the envelope dimensions specified in target_box, has a bottom and a front wall,
   // with standoffs, button guides, ventilation holes, and a rectangular opening for USB cable penetration.
   // dev_board_type: Entry in the ESP32_BOARDS array (not the index, should be ESP32_BOARDS[index].)
   // target_box: (Array[3]) The box that the mount has to fit into. The fit is asserted.
   // front_offset: The distance that the usb-end standoffs should be offset from the inside of the front wall.
   // usb_cable_aperture: (Array[2]) The rectangular opening to allow for insertion of the cable
   // button_shaft_dia: The diameter of the cylinder that button actuators will slide through.
   // wall_thickness: The thickness of the solid front wall and bottom.

   VENTILATION_HOLE_DIA = 3.0 * mm;
   VENTILATION_HOLE_PITCH = VENTILATION_HOLE_DIA + 2.0 * mm;

   translate([0, wall_thickness, 0])
   {   
      // Base with standoffs
      difference()
      {
         echo("Net Button Shaft Length: ", button_shaft_length(dev_board_type, wall_thickness));
         button_hole_dia = button_shaft_dia + 0.75;

         union()
         {
            controller_base(dev_board_type, target_box, front_offset, wall_thickness, 0.0, false);

            // Button slides
            translate([pin_x_offset(dev_board_type, target_box), pin_y_offset(dev_board_type, front_offset, target_box), 0])
            {
               slide_dia = button_hole_dia + wall_thickness;
               translate([pcb_button_offset_x(dev_board_type), pcb_button_offset_y(dev_board_type), 0])
               {
                  cylinder(h=button_shaft_length(dev_board_type, wall_thickness), d=slide_dia);
               }
                     
               translate([pcb_standoff_rect(dev_board_type)[0]-pcb_button_offset_x(dev_board_type), pcb_button_offset_y(dev_board_type), 0])
               {
                  cylinder(h=button_shaft_length(dev_board_type, wall_thickness), d=slide_dia);
               }
            }
         }

         translate([pin_x_offset(dev_board_type, target_box), pin_y_offset(dev_board_type, front_offset, target_box), -0.01])
         {
            // Holes for buttons
            translate([pcb_button_offset_x(dev_board_type), pcb_button_offset_y(dev_board_type), 0])
            {
               cylinder(h=button_shaft_length(dev_board_type, wall_thickness)+2.0, d=button_hole_dia);
            }
                  
            translate([pcb_standoff_rect(dev_board_type)[0]-pcb_button_offset_x(dev_board_type), pcb_button_offset_y(dev_board_type), 0])
            {
               cylinder(h=button_shaft_length(dev_board_type, wall_thickness)+2.0, d=button_hole_dia);
            }

            // Ventilation Holes
            ventilation_x_offset = VENTILATION_HOLE_PITCH/2.0 + button_hole_dia;
            ventilation_y_offset = button_hole_dia*2.0;
            hole_rect = 
            [
               pcb_standoff_rect(dev_board_type)[0] - ventilation_x_offset - pcb_standoff_pin_dia(dev_board_type), 
               pcb_standoff_rect(dev_board_type)[1] - ventilation_y_offset - pcb_standoff_pin_dia(dev_board_type)
            ];
            translate([ventilation_x_offset, ventilation_y_offset, -0.1])
            {
               rectangular_hole_pattern(
                  rect = hole_rect, 
                  hole_dia = VENTILATION_HOLE_DIA, 
                  hole_pitch = VENTILATION_HOLE_PITCH, 
                  hole_depth = 2.0*wall_thickness
               );
            }
         }
      }

      // Front wall
      difference()
      {
         translate([0, -wall_thickness, 0])
         {
            cube([target_box[0], wall_thickness, target_box[2]]);
         }

         // Cutout for USB
         cutout_x_offset = pin_x_offset(dev_board_type, target_box)-usb_cable_aperture[0]/2.0+pcb_usb_x_offset(dev_board_type);
         translate([cutout_x_offset, -wall_thickness/2.0-1.0, pcb_standoff_support_height(dev_board_type)-pcb_usb_z_offset(dev_board_type)])
         {
            cube([usb_cable_aperture[0], wall_thickness*2.0, usb_cable_aperture[1]]);
         }
      }

      // Gussets on sides to provide more strength
      gusset_length = target_box[2] * 0.325;
      translate([wall_thickness, -wall_thickness, 1.0]) rotate([0, 0, 90]) gusset(gusset_length, wall_thickness);
      translate([target_box[0], -wall_thickness, 1.0]) rotate([0, 0, 90]) gusset(gusset_length, wall_thickness);
   }

} // esp32_pcb_mount()
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

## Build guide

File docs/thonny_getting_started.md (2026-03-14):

# Getting Started with Thonny & CircuitPython
*Introduction to Engineering Course — Week 4: Software Engineering*

---

## What Is Thonny?

Thonny is a free Python editor designed for beginners. For this course it serves as your complete development environment for writing, saving, and running CircuitPython code on your ESP32 board — all over a single USB cable. No WiFi needed.

| | |
|---|---|
| **Write** | code in the top editor pane |
| **Save** | the file to your board with Ctrl+S |
| **Watch** | your board restart and run the new code automatically |
| **Debug** | using the REPL shell at the bottom — `print()` output appears here |

---

## Before Class: Install Thonny

### Install Thonny

1. Go to **https://thonny.org** and download the appropriate installer for your computer.
2. Run the installer with all default options.
3. Launch Thonny. On first run it may ask your experience level — choose **"Standard"**.

### Configure Thonny for CircuitPython

1. Plug your ESP32 board into the laptop via USB.
2. In Thonny, go to **Tools → Options** and click the **Interpreter** tab.
3. From the first dropdown, select **"CircuitPython (generic)"**.
4. From the port dropdown, choose the COM port you noted in Step 1 (e.g., COM3).
5. Click **OK**.

> ✅ **Success:** The bottom pane of Thonny will show a `>>>` prompt. This is the REPL — your live connection to the board. Type `print("hello")` and press Enter to confirm it works.

---

## The Thonny Interface

| Area | What it does |
|---|---|
| **Top editor pane** | Where you write and edit your code. |
| **Bottom shell / REPL** | Live connection to the board. Shows `print()` output and errors. You can type Python here interactively. *REPL stands for Read-Eval-Print-Loop. It is an interactive computer programming environment that takes single user inputs (read), executes them (evaluate), returns the result to the screen (print), and repeats this process in a loop.*|
| **File browser** | View → Files — shows files on both your laptop AND the board. Open your code files directly from the board here. |
| **Status bar** | Bottom-right corner shows the connected board and COM port. |

---

## Your Daily Coding Workflow

### Step 1 — Open code.py from the Board

1. Go to **View → Files** to show the file browser panel.
2. In the lower half of the panel ("MicroPython device"), find **code.py** and double-click it.
3. It opens in the editor pane, ready to edit.

Note that when Thonny connects to the board initially, it stops any program running on it.
To start the currently loaded program, type **Ctrl+D** in the REPL.

Note that if the program loaded on the board is running, you'll need to press the Stop button in the toolbar (or type **Ctrl+C** in the REPL) before editing and saving code.

**NOTE:** In CircuitPython, the board can either be running the REPL (allowing files to be opened and saved), or it can be running the program. Not both at the same time. If you attempt to save an open file when the program is running, you'll see a nasty error alert pop up. This won't cause any problems, but it will remind you to stop the program before attempting to save.

### Step 2 — Edit the Code

- Make your changes in the editor pane.

### Step 3 — Save and Run

- **Ctrl+S** saves the file back to the board.
- You'll need to type **Ctrl+D** in the REPL to restart the program running.
- Watch the REPL shell — your `print()` statements appear here as the code runs, as well as any errors that your code produces.

### Step 4 — Use the REPL to Explore

- Press the Stop button in the toolbar or type **Ctrl+C** in the REPL to interrupt running code and get the `>>>` prompt.
- Type Python commands directly to test ideas without saving a file:
  - `import board` — then...
  - `dir(board)` — lists all available pin names for your board
- Press **Ctrl+D** to soft-reset the board and resume running code.py.

---

## Key Shortcuts to Know

| Shortcut | What it does |
|---|---|
| **Ctrl+S** | Save file to board (triggers auto-restart) |
| **Ctrl+C** | Interrupt running code → get `>>>` prompt |
| **Ctrl+D** | Soft reset → resume running code.py |
| **Ctrl+Z** | Undo last edit |
| **Ctrl+F** | Find text in the editor |

---

## Troubleshooting

| Problem | Fix |
|---|---|
| **No `>>>` in the REPL shell** | Check the COM port in Tools → Options → Interpreter. Try unplugging and re-plugging the USB cable. |
| **"Port not found" error** | The board isn't recognized. Check Device Manager to verify that the board is recognized as a COM port or try a different USB cable — some cables are power-only. |
| **Sensor read errors in the REPL** | DHT11 errors are normal occasionally — the code handles them. Persistent errors suggest a loose wire on the sensor data pin. |
| **Board not visible in file browser** | Make sure Thonny is connected (`>>>` in REPL). Click View → Files if the panel isn't showing. |
| **Can't save edited file** | Stop the running program by pressing the Stop button in the toolbar or **Ctrl+C** in the REPL and try again. |

---

## REPL Cheat Sheet — Useful Examples

Type these directly at the `>>>` prompt to explore your board:

```python
import board                          # load the board module
dir(board)                            # list all pin names on your board
```

```python
import board
import neopixel                       # load libraries
leds = neopixel.NeoPixel(board.IO13, 10) # Create a NeoPixel object to control the LED strip
leds.fill((255, 0, 0))                # turn all LEDs red
leds.fill((0, 0, 0))                  # turn LEDs off
leds[4] =((0, 0, 255))                # Make LED #4 (fifth LED) blue
pixels.show()                         # needed if auto_write=False
```

---

## Further Reading

- **Adafruit "Welcome to CircuitPython" guide:** https://learn.adafruit.com/welcome-to-circuitpython
- **CircuitPython library docs:** https://docs.circuitpython.org
- **Thonny home page:** https://thonny.org
- **CircuitPython library bundle (download libraries here):** https://circuitpython.org/libraries

---

*Introduction to Engineering Course — Keep this sheet, you'll refer to it every week.*

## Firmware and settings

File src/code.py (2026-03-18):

# This is the main loop definition for the Intro to Engineering device code.
#
# The following libraries must be installed on the board from the CircuitPython bundle file
# https://github.com/adafruit/Adafruit_CircuitPython_Bundle
# adafruit_dht.mpy
# adafruit_ds18x20.mpy
# adafruit_pixelbuf.mpy
# neopixel.mpy

import time
import board
import digitalio as dio
import neopixel
import adafruit_dht as dht_lib
import keypad
import test_mode        # Default test mode
import temp_mode        # Display temperature and humidity
import random_mode      # Random colors mode

# The Neopixel library provides the control interface for WS2812 addressable LEDs
# Neopixel library page: https://learn.adafruit.com/circuitpython-essentials/circuitpython-neopixel
# Neopixel library documentation: https://docs.circuitpython.org/projects/neopixel/en/latest/

# DHT library documentation page: https://docs.circuitpython.org/projects/dht/en/latest/
# AM2302/DHT22 datasheet: https://cdn-shop.adafruit.com/datasheets/Digital+humidity+and+temperature+sensor+AM2302.pdf
# Second source for datasheet: https://cdn.sparkfun.com/assets/f/7/d/9/c/DHT22.pdf

# To find out what the pin names are for the board, use dir(board)

# Running the script described in Download Project Bundle on this page will help identify aliases:
# https://learn.adafruit.com/circuitpython-essentials/circuitpython-pins-and-modules

# Define some time constants for use later.
SLEEP_TIME_BETWEEN_LOOPS = 0.03         # (sec) Defines the sleep time between loop iterations.
OB_LED_UPDATE_PERIOD = 1.0              # (sec) Defines the time between onboard LED updates
DHT_READ_PERIOD = 10.0                  # (sec) Defines the time between DHT reads

# Define the device pins that will be used
OB_LED_PIN = board.IO2      # Onboard blue LED pin for this board
NEO_PIN = board.IO13        # WS2812B LED string data pin
DHT_PIN = board.IO18        # DHT11 sensor data pin
BUTTON_PIN = board.IO0      # Mode button pin (using BOOT button on the board)

# Setup the onboard LED as an output. We'll blink this LED.
onboard_led = dio.DigitalInOut(OB_LED_PIN)
onboard_led.direction = dio.Direction.OUTPUT
onboard_led.value = False   # Set the initial state of the onboard LED

# Define the object that will represent our LED string
NUM_LEDS = 10               # The number of LEDs in our string
INITIAL_BRIGHTNESS = 0.1    # The initial brightness of the LED string
leds = neopixel.NeoPixel(NEO_PIN, NUM_LEDS)
leds.brightness = INITIAL_BRIGHTNESS

# Define the temperature sensor object. Use DHT22 for a DHT22.
dht = dht_lib.DHT11(DHT_PIN)

# Define the buttons object for handling button input
buttons = keypad.Keys((BUTTON_PIN,), value_when_pressed=False, pull=True)

# Define the list of supported modes
MODE_LIST = [
    temp_mode, 		# The temperature & humidity display mode
    random_mode,	# The random colors mode
    test_mode		# The default test mode
]

# A few miscellaneous global variables
ob_LED_last_time = time.monotonic()     # The last time the onboard LED was updated
dht_read_last_time = time.monotonic()   # The last time the DHT sensor was updated

# Current status. This data structure contains the current status of the device,
# all in one place for convenience. It is updated by various functions as information
# changes.
current_status = {
    "mode": 0,				# The current device mode (number)
    "mode_name": "",		# The name of the current mode. Filled in when status is retrieved.
    "temperature": 0.0,		# The current temperature (deg. Fahrenheit). Filled in on update.
    "humidity": 0.0,		# The current humidity (%). Filled in on update.
    "max_temp": 0.0,		# The maximum temperature detected. Filled in on update.
    "min_temp": 10000.0,	# The minimum temperature detected. Filled in on update.
    "max_humidity": 0.0,	# The maximum humidity detected. Filled in on update.
    "min_humidity": 100.0, 	# The minimum humidity detected. Filled in on update.
    "modes": {},			# The list of modes
}
current_status["modes"] = [mode_obj.get_name() for mode_obj in MODE_LIST]


# Define utility functions update and get the device status.

def _set_mode(new_mode):
    """ Private function to set the current mode to the mode passed in.
        Args:
            new_mode (integer): The mode number to change to.
    """
    global current_status
    global MODE_LIST
    current_mode = current_status["mode"]
    
    if 0 <= new_mode < len(MODE_LIST):
        print(f"Leaving mode: {current_mode}")
        MODE_LIST[current_mode].reset(current_status, leds) # Leaving the old mode
        current_status["mode"] = new_mode
        current_status["mode_name"] = MODE_LIST[new_mode].get_name()
        print(f"Entering mode: {new_mode}")
        MODE_LIST[new_mode].init(current_status, leds)  # Entering the new mode
        return True
    
    return False


def _get_status():
    """ Private function to return the current environmental monitor status.
        Args: none.
    """
    global current_status
    
    return current_status


# The Super Loop. Runs forever.
while True:

    # Update the state of the onboard LED
    if ( (time.monotonic() - ob_LED_last_time) > OB_LED_UPDATE_PERIOD ):
        onboard_led.value = not onboard_led.value # Toggle LED state
        ob_LED_last_time = time.monotonic()

    # Check to see if there has been a button event
    event = buttons.events.get()
    if event:
        if event.pressed:
            # Increment the mode
            old_mode = current_status["mode"]
            _set_mode( (old_mode + 1) % len(MODE_LIST) )

    # Read the DHT11
    if (time.monotonic() - dht_read_last_time) > DHT_READ_PERIOD:
        try:
            temp = ( dht.temperature * (9/5) ) + 32 # Converted to Fahrenheit
            humid = dht.humidity
            print("Temp: {:.1f}F Humidity: {}% ".format(temp, humid))
            current_status["temperature"] = temp
            current_status["humidity"] = humid
            # Update min and max temps, if appropriate
            if temp > current_status["max_temp"]:
                current_status["max_temp"] = temp
            elif temp < current_status["min_temp"]: 
                current_status["min_temp"] = temp 
            if humid > current_status["max_humidity"]:
                current_status["max_humidity"] = humid 
            elif humid < current_status["min_humidity"]:
                current_status["min_humidity"] = humid 
        except RuntimeError as error:
            print(error.args[0])

        dht_read_last_time = time.monotonic()

    # Tell the mode to update
    MODE_LIST[current_status["mode"]].update(current_status, leds)
    
    # Sleep for just a bit so that we aren't in a tight loop and hogging the processor.
    time.sleep(SLEEP_TIME_BETWEEN_LOOPS)
    

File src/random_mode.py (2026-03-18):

# Defines the random_mode
#    The random mode randomly generates colors for each of the LEDs and
#    then fades them. Updates the string every time that the update() 
#    function is called.

import time
import random

UPDATE_PERIOD = 0.075          # 10 times per second (100 msec)
last_time = time.monotonic() # This global variable will keep track of when we last updated.

BLACK = (0, 0, 0)       # Define black for convenience

GRANULARITY = 10        # The granularity we will use. RGB components will be multiples of this value
FADE_CONST = 2          # The amount that we fade each iteration.


def _random_color(granularity):
    """ Private function that returns a random color tuple.

    Args:
        granularity (integer): The RGB components will be in multiples of this value from 0 to < 255.
    """
    return (random.randrange(0, 255, granularity), random.randrange(0, 255, granularity), random.randrange(0, 255, granularity))


def _fade(pixel, fade):
    """Private function that fades a pixel by the given amount

    Args:
        pixel (color tuple): The color to fade.
        fade (integer): The amount to fade each time we're called
    """
    pixel_list = list(pixel)
    for i in range(0, len(pixel_list)):
        pixel_list[i] = pixel_list[i] - fade if (pixel_list[i] - fade) > 0 else 0

    return tuple(pixel_list)


def get_name():
    """ Returns the name of the mode. """
    return "Random Color"


def init(status, leds):
    """
    Initializes the mode.
    Args:
        status (current_status object): The device's current status.
        leds (NeoPixel object): The NeoPixel object that controls the LEDs.
    """
    global last_time

    for i in range(0, len(leds)):
        leds[i] = _random_color(GRANULARITY)

    last_time = time.monotonic()    


loop_counter = 0
time_accumulator = 0.0

def update(status, leds):
    """
    Performs the update function for this mode.
    Args:
        status (current_status object): The device's current status.
        leds (NeoPixel object): The NeoPixel object that controls the LEDs.
    """
    global last_time
    global color_index
    global loop_counter
    global time_accumulator
    
    if ( (time.monotonic() - last_time) > UPDATE_PERIOD ):
        for i in range(0, len(leds)):
            leds[i] = _fade(leds[i], FADE_CONST)
            # If we have faded to black, assign a new random color
            if (leds[i] == BLACK):
                leds[i] = _random_color(GRANULARITY)

        # Show the average update time
        loop_counter += 1
        time_accumulator += (time.monotonic() - last_time)
        if ( (loop_counter % 50) == 0 ):
            print("Average update period: {:.1f} msec".format(time_accumulator/50.0*1000.0))
            loop_counter = 0
            time_accumulator = 0.0

        last_time = time.monotonic()


def reset(status, leds):
    """
    Clears the mode state, ready for the next mode.

    Args:
        status (current_status object): The device's current status.
        leds (NeoPixel object): The NeoPixel object that controls the LEDs.
    """
    leds.fill(BLACK) # Turn all of the LEDs off

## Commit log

2026-03-14 Initial commit, circuit test code only.
    [LED_Encl_Cutout.stl, LED_Enclosure.stl, button.stl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]
2026-03-31 Adding STL for example base design and Week 4.
    [Engineering_Club_Base.stl]
